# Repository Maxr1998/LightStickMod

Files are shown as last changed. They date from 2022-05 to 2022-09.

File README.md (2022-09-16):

# Light Stick Mod

Modding the LOOΠΔ light stick with a custom PCB/firmware, rechargeable battery and a companion Android app for wireless control.

<p align="center">
Photo of the finished light stick
</p>

## [pcb](pcb)

Designed in KiCAD, manufactured by JLCPCB. Uses the ESP32 as a controller.

## [firmware](firmware)

Built with [esphome.io](https://esphome.io).
Supports WiFi control, integrates with Home Assistant, introduces [animated effects](https://gfycat.com/grandcharminghogget).  
Thanks to deep sleep support, idle battery drain can be kept to a minimum.

## [app](app)

Companion app for Android to allow wireless control via Bluetooth LE. Written in Kotlin, using JetPack Compose for the UI.

## [build log](build-log.md)

Write-up on how I modded it.

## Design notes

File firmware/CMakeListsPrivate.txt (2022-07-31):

# !!! WARNING !!! AUTO-GENERATED FILE, PLEASE DO NOT MODIFY IT AND USE
# https://docs.platformio.org/page/projectconf/section_env_build.html#build-flags
#
# If you need to override existing CMake configuration or add extra,
# please create `CMakeListsUser.txt` in the root of project.
# The `CMakeListsUser.txt` will not be overwritten by PlatformIO.

set(CMAKE_CONFIGURATION_TYPES "lightstick" CACHE STRING "Build Types reflect PlatformIO Environments" FORCE)

SET(CMAKE_C_COMPILER "$ENV{HOME}/.platformio/packages/toolchain-xtensa32/bin/xtensa-esp32-elf-gcc")
SET(CMAKE_CXX_COMPILER "$ENV{HOME}/.platformio/packages/toolchain-xtensa32/bin/xtensa-esp32-elf-g++")
SET(CMAKE_CXX_FLAGS "-fno-rtti -fno-exceptions -std=gnu++11 -Wno-sign-compare -Wno-unused-but-set-variable -Wno-unused-variable -fno-exceptions -Os -g3 -Wall -nostdlib -Wpointer-arith -Wno-error=unused-but-set-variable -Wno-error=unused-variable -mlongcalls -ffunction-sections -fdata-sections -fstrict-volatile-bitfields -Wno-error=deprecated-declarations -Wno-error=unused-function -Wno-unused-parameter -Wno-sign-compare -fstack-protector -fexceptions -Werror=reorder")
SET(CMAKE_C_FLAGS "-std=gnu99 -Wno-old-style-declaration -Wno-sign-compare -Wno-unused-but-set-variable -Wno-unused-variable -fno-exceptions -Os -g3 -Wall -nostdlib -Wpointer-arith -Wno-error=unused-but-set-variable -Wno-error=unused-variable -mlongcalls -ffunction-sections -fdata-sections -fstrict-volatile-bitfields -Wno-error=deprecated-declarations -Wno-error=unused-function -Wno-unused-parameter -Wno-sign-compare -fstack-protector -fexceptions -Werror=reorder")

SET(CMAKE_C_STANDARD 99)
set(CMAKE_CXX_STANDARD 11)

SET(CMAKE_BUILD_DIR "${CMAKE_CURRENT_LIST_DIR}/.esphome/build/lightstick")

#if (CMAKE_BUILD_TYPE MATCHES "lightstick")
    add_definitions(-DPLATFORMIO=60103)
    add_definitions(-DARDUINO_ESP32_DEV)
    add_definitions(-DESPHOME_LOG_LEVEL=ESPHOME_LOG_LEVEL_INFO)
    add_definitions(-DUSE_ARDUINO)
    add_definitions(-DUSE_ESP32)
    add_definitions(-DUSE_ESP32_FRAMEWORK_ARDUINO)
    add_definitions(-DUSE_ESP32_VARIANT_ESP32)
    add_definitions(-DESP32)
    add_definitions(-DESP_PLATFORM)
    add_definitions(-DF_CPU=240000000L)
    add_definitions(-DHAVE_CONFIG_H)
    add_definitions(-DMBEDTLS_CONFIG_FILE=\"mbedtls/esp_config.h\")
    add_definitions(-DARDUINO=10805)
    add_definitions(-DARDUINO_ARCH_ESP32)
    add_definitions(-DARDUINO_VARIANT=\"esp32\")
    add_definitions(-DARDUINO_BOARD=\"Espressif\ ESP32\ Dev\ Module\")

    include_directories("${CMAKE_CURRENT_LIST_DIR}/")
    include_directories("${CMAKE_BUILD_DIR}/include")
    include_directories("${CMAKE_BUILD_DIR}/src")
    include_directories("${CMAKE_BUILD_DIR}/.pio/libdeps/lightstick/ArduinoJson/src")
    include_directories("${CMAKE_BUILD_DIR}/.pio/libdeps/lightstick/ESPAsyncWebServer-esphome/src")
    include_directories("${CMAKE_BUILD_DIR}/.pio/libdeps/lightstick/AsyncTCP-esphome/src")
    include_directories("$ENV{HOME}/.platformio/packages/framework-arduinoespressif32/libraries/ESPmDNS/src")
    include_directories("$ENV{HOME}/.platformio/packages/framework-arduinoespressif32/libraries/Update/src")
    include_directories("$ENV{HOME}/.platformio/packages/framework-arduinoespressif32/libraries/FS/src")
    include_directories("$ENV{HOME}/.platformio/packages/framework-arduinoespressif32/libraries/WiFi/src")
    include_directories("$ENV{HOME}/.platformio/packages/framework-arduinoespressif32/tools/sdk/include/config")
    include_directories("$ENV{HOME}/.platformio/packages/framework-arduinoespressif32/tools/sdk/include/app_trace")
    include_directories("$ENV{HOME}/.platformio/packages/framework-arduinoespressif32/tools/sdk/include/app_update")
    include_directories("$ENV{HOME}/.platformio/packages/framework-arduinoespressif32/tools/sdk/include/asio")
    include_directories("$ENV{HOME}/.platformio/packages/framework-arduinoespressif32/tools/sdk/include/bootloader_support")
    include_directories("$ENV{HOME}/.platformio/packages/framework-arduinoespressif32/tools/sdk/include/bt")
    include_directories("$ENV{HOME}/.platformio/packages/framework-arduinoespressif32/tools/sdk/include/coap")
    include_directories("$ENV{HOME}/.platformio/packages/framework-arduinoespressif32/tools/sdk/include/console")
    include_directories("$ENV{HOME}/.platformio/packages/framework-arduinoespressif32/tools/sdk/include/driver")
    include_directories("$ENV{HOME}/.platformio/packages/framework-arduinoespressif32/tools/sdk/include/efuse")
    include_directories("$ENV{HOME}/.platformio/packages/framework-arduinoespressif32/tools/sdk/include/esp-tls")
    include_directories("$ENV{HOME}/.platformio/packages/framework-arduinoespressif32/tools/sdk/include/esp32")
    include_directories("$ENV{HOME}/.platformio/packages/framework-arduinoespressif32/tools/sdk/include/esp_adc_cal")
    include_directories("$ENV{HOME}/.platformio/packages/framework-arduinoespressif32/tools/sdk/include/esp_event")
    include_directories("$ENV{HOME}/.platformio/packages/framework-arduinoespressif32/tools/sdk/include/esp_http_client")
    include_directories("$ENV{HOME}/.platformio/packages/framework-arduinoespressif32/tools/sdk/include/esp_http_server")
    include_directories("$ENV{HOME}/.platformio/packages/framework-arduinoespressif32/tools/sdk/include/esp_https_ota")
    include_directories("$ENV{HOME}/.platformio/packages/framework-arduinoespressif32/tools/sdk/include/esp_https_server")
    include_directories("$ENV{HOME}/.platformio/packages/framework-arduinoespressif32/tools/sdk/include/esp_ringbuf")
    include_directories("$ENV{HOME}/.platformio/packages/framework-arduinoespressif32/tools/sdk/include/esp_websocket_client")
    include_directories("$ENV{HOME}/.platformio/packages/framework-arduinoespressif32/tools/sdk/include/espcoredump")
    include_directories("$ENV{HOME}/.platformio/packages/framework-arduinoespressif32/tools/sdk/include/ethernet")
    include_directories("$ENV{HOME}/.platformio/packages/framework-arduinoespressif32/tools/sdk/include/expat")
    include_directories("$ENV{HOME}/.platformio/packages/framework-arduinoespressif32/tools/sdk/include/fatfs")
    include_directories("$ENV{HOME}/.platformio/packages/framework-arduinoespressif32/tools/sdk/include/freemodbus")
    include_directories("$ENV{HOME}/.platformio/packages/framework-arduinoespressif32/tools/sdk/include/freertos")
    include_directories("$ENV{HOME}/.platformio/packages/framework-arduinoespressif32/tools/sdk/include/heap")
    include_directories("$ENV{HOME}/.platformio/packages/framework-arduinoespressif32/tools/sdk/include/idf_test")
    include_directories("$ENV{HOME}/.platformio/packages/framework-arduinoespressif32/tools/sdk/include/jsmn")
    include_directories("$ENV{HOME}/.platformio/packages/framework-arduinoespressif32/tools/sdk/include/json")
    include_directories("$ENV{HOME}/.platformio/packages/framework-arduinoespressif32/tools/sdk/include/libsodium")
    include_directories("$ENV{HOME}/.platformio/packages/framework-arduinoespressif32/tools/sdk/include/log")
    include_directories("$ENV{HOME}/.platformio/packages/framework-arduinoespressif32/tools/sdk/include/lwip")
    include_directories("$ENV{HOME}/.platformio/packages/framework-arduinoespressif32/tools/sdk/include/mbedtls")
    include_directories("$ENV{HOME}/.platformio/packages/framework-arduinoespressif32/tools/sdk/include/mdns")
    include_directories("$ENV{HOME}/.platformio/packages/framework-arduinoespressif32/tools/sdk/include/micro-ecc")
    include_directories("$ENV{HOME}/.platformio/packages/framework-arduinoespressif32/tools/sdk/include/mqtt")
    include_directories("$ENV{HOME}/.platformio/packages/framework-arduinoespressif32/tools/sdk/include/newlib")
    include_directories("$ENV{HOME}/.platformio/packages/framework-arduinoespressif32/tools/sdk/include/nghttp")
    include_directories("$ENV{HOME}/.platformio/packages/framework-arduinoespressif32/tools/sdk/include/nvs_flash")
    include_directories("$ENV{HOME}/.platformio/packages/framework-arduinoespressif32/tools/sdk/include/openssl")
    include_directories("$ENV{HOME}/.platformio/packages/framework-arduinoespressif32/tools/sdk/include/protobuf-c")
    include_directories("$ENV{HOME}/.platformio/packages/framework-arduinoespressif32/tools/sdk/include/protocomm")
    include_directories("$ENV{HOME}/.platformio/packages/framework-arduinoespressif32/tools/sdk/include/pthread")
    include_directories("$ENV{HOME}/.platformio/packages/framework-arduinoespressif32/tools/sdk/include/sdmmc")
    include_directories("$ENV{HOME}/.platformio/packages/framework-arduinoespressif32/tools/sdk/include/smartconfig_ack")
    include_directories("$ENV{HOME}/.platformio/packages/framework-arduinoespressif32/tools/sdk/include/soc")
    include_directories("$ENV{HOME}/.platformio/packages/framework-arduinoespressif32/tools/sdk/include/spi_flash")
    include_directories("$ENV{HOME}/.platformio/packages/framework-arduinoespressif32/tools/sdk/include/spiffs")
    include_directories("$ENV{HOME}/.platformio/packages/framework-arduinoespressif32/tools/sdk/include/tcp_transport")
    include_directories("$ENV{HOME}/.platformio/packages/framework-arduinoespressif32/tools/sdk/include/tcpip_adapter")
    include_directories("$ENV{HOME}/.platformio/packages/framework-arduinoespressif32/tools/sdk/include/ulp")
    include_directories("$ENV{HOME}/.platformio/packages/framework-arduinoespressif32/tools/sdk/include/unity")
    include_directories("$ENV{HOME}/.platformio/packages/framework-arduinoespressif32/tools/sdk/include/vfs")
    include_directories("$ENV{HOME}/.platformio/packages/framework-arduinoespressif32/tools/sdk/include/wear_levelling")
    include_directories("$ENV{HOME}/.platformio/packages/framework-arduinoespressif32/tools/sdk/include/wifi_provisioning")
    include_directories("$ENV{HOME}/.platformio/packages/framework-arduinoespressif32/tools/sdk/include/wpa_supplicant")
    include_directories("$ENV{HOME}/.platformio/packages/framework-arduinoespressif32/tools/sdk/include/xtensa-debug-module")
    include_directories("$ENV{HOME}/.platformio/packages/framework-arduinoespressif32/tools/sdk/include/esp-face")
    include_directories("$ENV{HOME}/.platformio/packages/framework-arduinoespressif32/tools/sdk/include/esp32-camera")
    include_directories("$ENV{HOME}/.platformio/packages/framework-arduinoespressif32/tools/sdk/include/fb_gfx")
    include_directories("$ENV{HOME}/.platformio/packages/framework-arduinoespressif32/cores/esp32")
    include_directories("$ENV{HOME}/.platformio/packages/framework-arduinoespressif32/variants/esp32")
    include_directories("$ENV{HOME}/.platformio/lib/Adafruit BME280 Library")
    include_directories("$ENV{HOME}/.platformio/lib/Adafruit Unified Sensor")
    include_directories("$ENV{HOME}/.platformio/lib/FastLED")
    include_directories("$ENV{HOME}/.platformio/packages/framework-arduinoespressif32/libraries/ArduinoOTA/src")
    include_directories("$ENV{HOME}/.platformio/packages/framework-arduinoespressif32/libraries/AsyncUDP/src")
    include_directories("$ENV{HOME}/.platformio/packages/framework-arduinoespressif32/libraries/AzureIoT/src")
    include_directories("$ENV{HOME}/.platformio/packages/framework-arduinoespressif32/libraries/BLE/src")
    include_directories("$ENV{HOME}/.platformio/packages/framework-arduinoespressif32/libraries/BluetoothSerial/src")
    include_directories("$ENV{HOME}/.platformio/packages/framework-arduinoespressif32/libraries/DNSServer/src")
    include_directories("$ENV{HOME}/.platformio/packages/framework-arduinoespressif32/libraries/EEPROM/src")
    include_directories("$ENV{HOME}/.platformio/packages/framework-arduinoespressif32/libraries/ESP32/src")
    include_directories("$ENV{HOME}/.platformio/packages/framework-arduinoespressif32/libraries/FFat/src")
    include_directories("$ENV{HOME}/.platformio/packages/framework-arduinoespressif32/libraries/HTTPClient/src")
    include_directories("$ENV{HOME}/.platformio/packages/framework-arduinoespressif32/libraries/HTTPUpdate/src")
    include_directories("$ENV{HOME}/.platformio/packages/framework-arduinoespressif32/libraries/HTTPUpdateServer/src")
    include_directories("$ENV{HOME}/.platformio/packages/framework-arduinoespressif32/libraries/NetBIOS/src")
    include_directories("$ENV{HOME}/.platformio/packages/framework-arduinoespressif32/libraries/Preferences/src")
    include_directories("$ENV{HOME}/.platformio/packages/framework-arduinoespressif32/libraries/SD/src")
    include_directories("$ENV{HOME}/.platformio/packages/framework-arduinoespressif32/libraries/SD_MMC/src")
    include_directories("$ENV{HOME}/.platformio/packages/framework-arduinoespressif32/libraries/SPI/src")
    include_directories("$ENV{HOME}/.platformio/packages/framework-arduinoespressif32/libraries/SPIFFS/src")
    include_directories("$ENV{HOME}/.platformio/packages/framework-arduinoespressif32/libraries/SimpleBLE/src")
    include_directories("$ENV{HOME}/.platformio/packages/framework-arduinoespressif32/libraries/Ticker/src")
    include_directories("$ENV{HOME}/.platformio/packages/framework-arduinoespressif32/libraries/WebServer/src")
    include_directories("$ENV{HOME}/.platformio/packages/framework-arduinoespressif32/libraries/WiFiClientSecure/src")
    include_directories("$ENV{HOME}/.platformio/packages/framework-arduinoespressif32/libraries/WiFiProv/src")
    include_directories("$ENV{HOME}/.platformio/packages/framework-arduinoespressif32/libraries/Wire/src")
    include_directories("$ENV{HOME}/.platformio/packages/toolchain-xtensa32/xtensa-esp32-elf/include/c++/5.2.0")
    include_directories("$ENV{HOME}/.platformio/packages/toolchain-xtensa32/xtensa-esp32-elf/include/c++/5.2.0/xtensa-esp32-elf")
    include_directories("$ENV{HOME}/.platformio/packages/toolchain-xtensa32/lib/gcc/xtensa-esp32-elf/5.2.0/include-fixed")
    include_directories("$ENV{HOME}/.platformio/packages/toolchain-xtensa32/lib/gcc/xtensa-esp32-elf/5.2.0/include")
    include_directories("$ENV{HOME}/.platformio/packages/toolchain-xtensa32/xtensa-esp32-elf/include")

    FILE(GLOB_RECURSE EXTRA_LIB_SOURCES
        ${CMAKE_BUILD_DIR}/.pio/libdeps/lightstick/*.*
    )
#endif()

FILE(GLOB_RECURSE SRC_LIST
    ${CMAKE_CURRENT_LIST_DIR}/*.*
    ${CMAKE_BUILD_DIR}/src/*.*
    ${CMAKE_BUILD_DIR}/lib/*.*
    ${CMAKE_BUILD_DIR}/test/*.*
)

list(APPEND SRC_LIST ${EXTRA_LIB_SOURCES})

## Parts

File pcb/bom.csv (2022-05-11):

Comment | Designator | Footprint | LCSC Part Number
10K | R1,R2 | 0805 | C17414
1K | R3,R4,R5,R6 | 0805 | C17513
10uF | C1 | 0805 | C32635
BC817 | Q1,Q2,Q3,Q4 | SOT-23-3 | C126908
AMS1117 | U1 | SOT-223 | C6186
ESP32 | U2 | SMD38 | C701342
Slide Switch | SW1 | SMD | C431541
6x6x5mm Tactile Switch | SW2 | SMD | C782827
JST PH1 2mm Connector 5 Pin | J1 | CONN-SMD | C146056

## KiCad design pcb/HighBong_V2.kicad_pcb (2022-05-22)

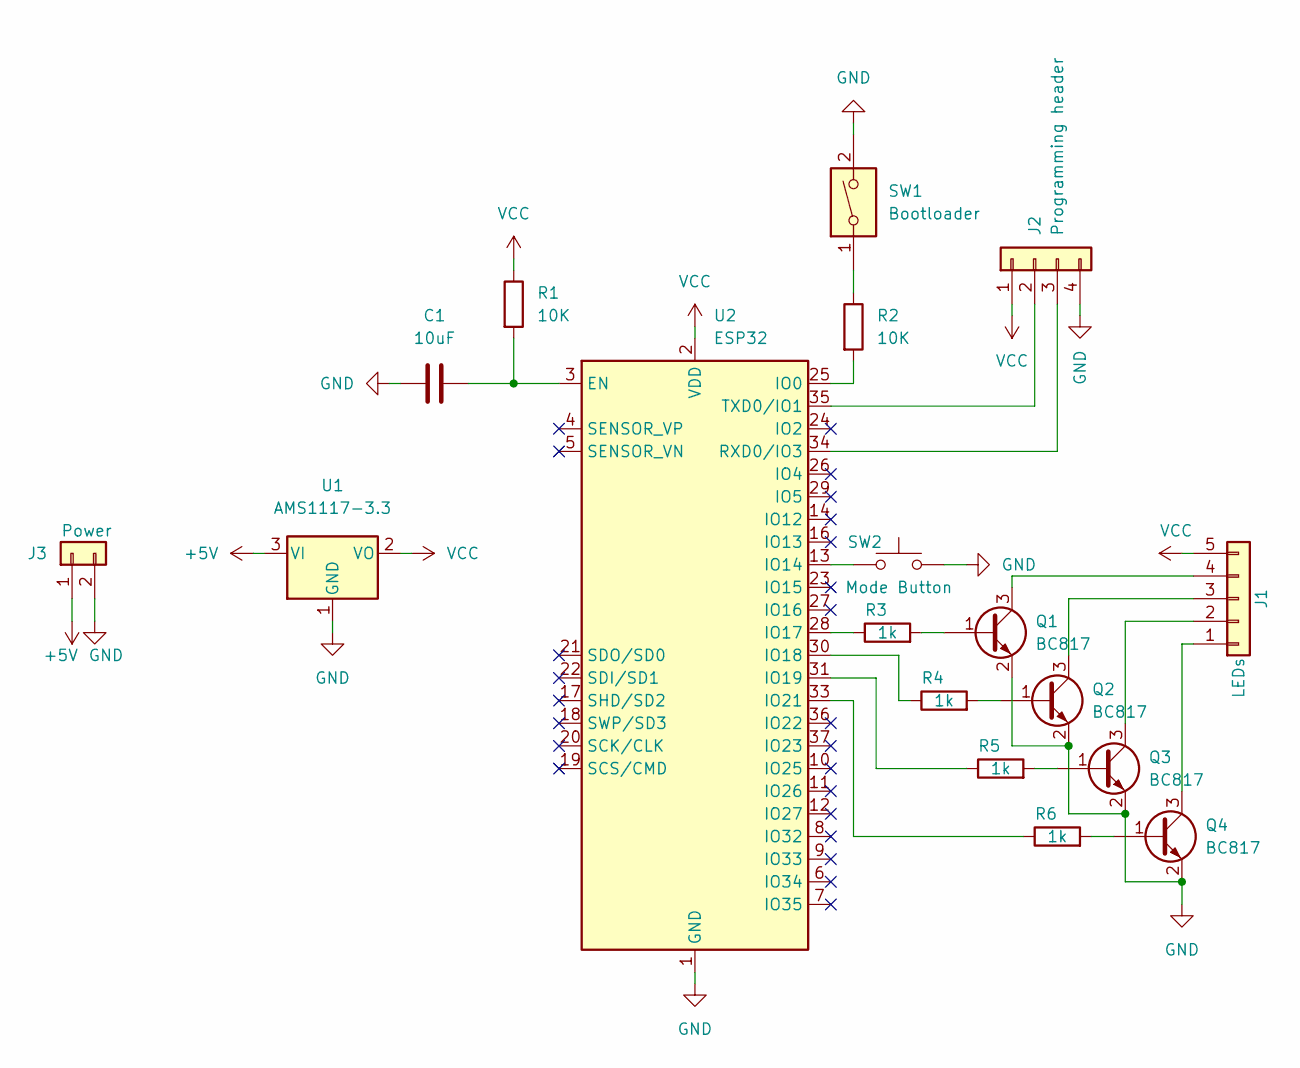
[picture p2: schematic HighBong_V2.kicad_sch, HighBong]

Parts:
C1: 10uF; C_0805_2012Metric_Pad1.18x1.45mm_HandSolder
J1: LEDs; JST_PH_B5B-PH-SM4-TB_1x05-1MP_P2.00mm_Vertical
J2: Programming header; PinHeader_1x04_P2.54mm_Vertical
J3: Power; JST_PH_B2B-PH-SM4-TB_1x02-1MP_P2.00mm_Vertical
Q1, Q2, Q3, Q4: BC817; SOT-23
R1, R2: 10K; R_0805_2012Metric_Pad1.20x1.40mm_HandSolder
R3, R4, R5, R6: 1k; R_0805_2012Metric_Pad1.20x1.40mm_HandSolder
SW1: Bootloader; KPS-1290
SW2: Mode Button; SW_Push_1P1T_NO_6x6mm_H9.5mm
U1: AMS1117-3.3; SOT-223-3_TabPin2
U2: ESP32; ESP32-WROOM-32

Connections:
+5V: J3.1, U1.3 (VI)
GND: C1.2, J2.4, J3.2, Q1.2 (E), Q2.2 (E), Q3.2 (E), Q4.2 (E), SW1.2, SW2.2, U1.1 (GND), U2.1 (GND), U2.15 (GND), U2.38 (GND), U2.39 (GND)
unnamed: C1.1, R1.2, U2.3 (EN)
unnamed: J1.1, Q4.3 (C)
unnamed: J1.2, Q3.3 (C)
unnamed: J1.3, Q2.3 (C)
unnamed: J1.4, Q1.3 (C)
unnamed: J2.2, U2.35 (TXD0/IO1)
unnamed: J2.3, U2.34 (RXD0/IO3)
unnamed: Q1.1 (B), R3.2
unnamed: Q2.1 (B), R4.2
unnamed: Q3.1 (B), R5.2
unnamed: Q4.1 (B), R6.2
unnamed: R2.1, SW1.1
unnamed: R2.2, U2.25 (IO0)
unnamed: R3.1, U2.28 (IO17)
unnamed: R4.1, U2.30 (IO18)
unnamed: R5.1, U2.31 (IO19)
unnamed: R6.1, U2.33 (IO21)
unnamed: SW2.1, U2.13 (IO14)
VCC: J1.5, J2.1, R1.1, U1.2 (VO), U2.2 (VDD)

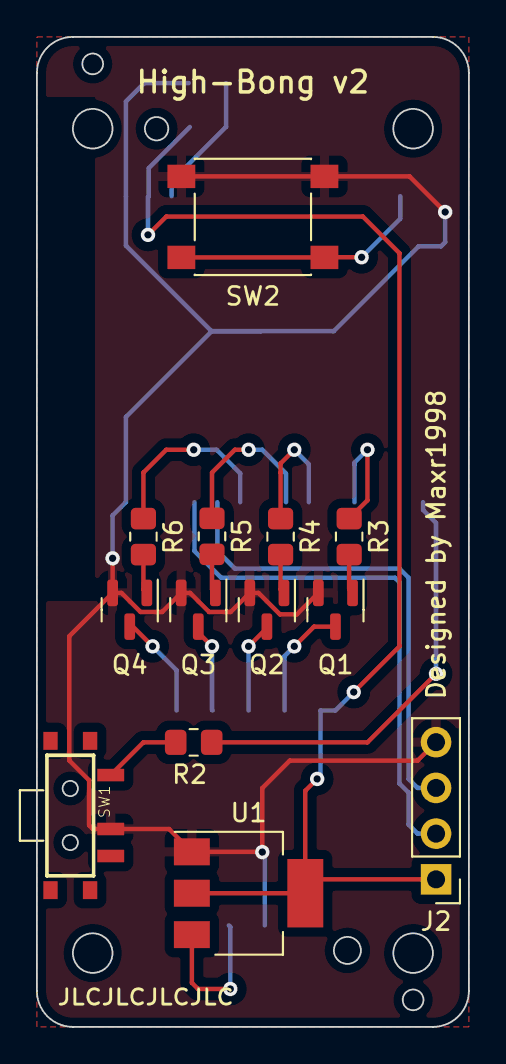
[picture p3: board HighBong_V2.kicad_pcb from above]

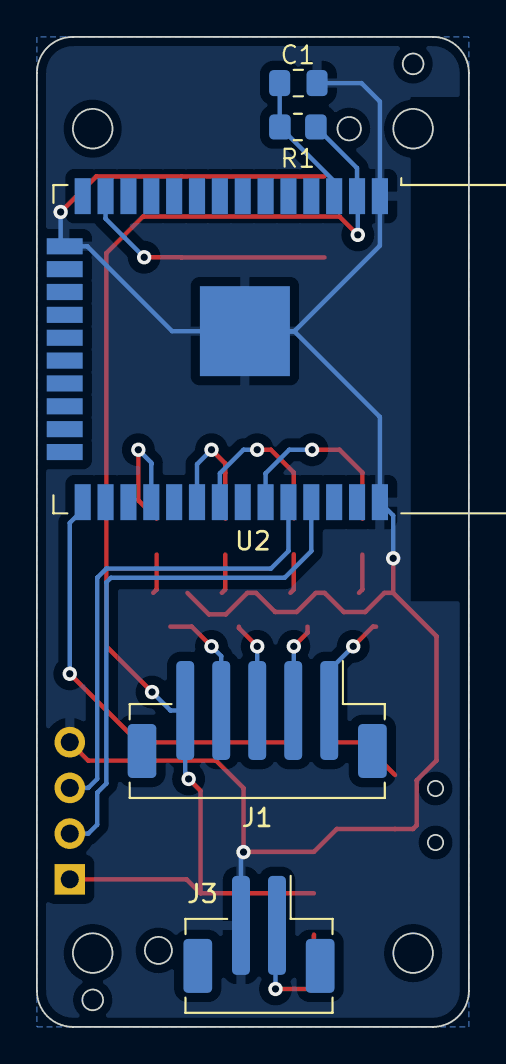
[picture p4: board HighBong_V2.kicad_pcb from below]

Board: 2 copper layers, 24.0 x 55.0 mm, 18 parts (5 on the bottom side), 21 nets.

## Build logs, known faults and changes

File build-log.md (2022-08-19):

# Build log

## Step 0: reverse-engineering and PCB design

First, I needed to understand how the light stick originally works.
Disassembly was very easy (only standard screws, yay!) and the PCB had some labels, which helped a lot.
To recreate the important properties for my own PCB, I had to do a lot of measuring,
did a few voltage readings, and carefully studied the design of the board.  
With that out of the way, I could create the [PCB](pcb).
Finding the correct components wasn't trivial, and I spent a lot of time picking the right transistor to control the LEDs.
For the rest, I selected equivalent parts where applicable, and added appropriate components for new behavior.
A bit of layouting and routing later, everything seemed fine, and I had a flawless design to put into production.
*Or so I thought.* More on that later.

## Step 1: PCB assembly

<p align="center">
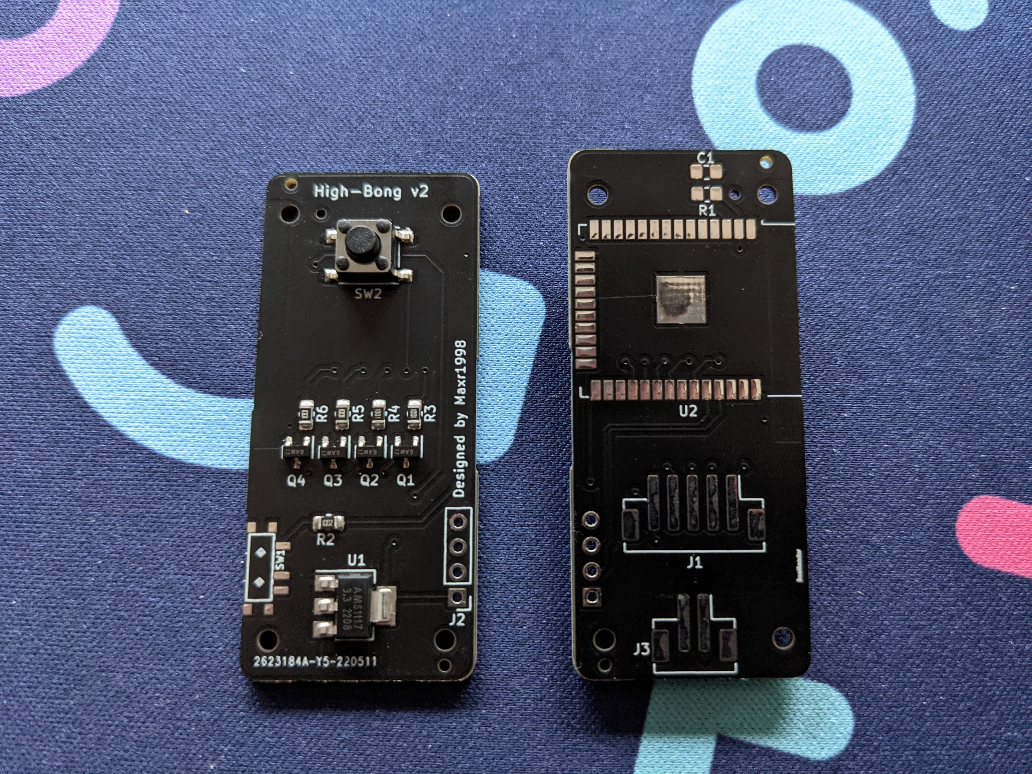
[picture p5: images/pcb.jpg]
PCB as delivered

</p>

…at least, partially.
Most components were already soldered by JLCPCB, since I chose to have one side of the board pre-assembled.
They did a very good job with it, in my opinion, just like on a previous order. It was also decently cheap.
Because I could only get one side assembled and them not having some parts, I needed to do the rest of the soldering myself.

<p align="center">
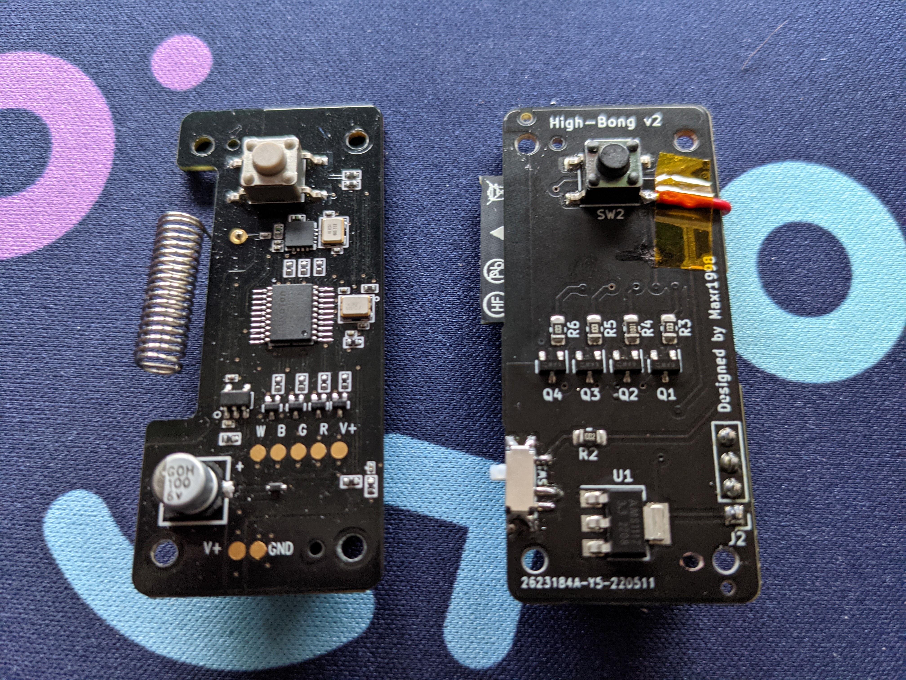
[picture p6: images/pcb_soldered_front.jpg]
PCB soldered front

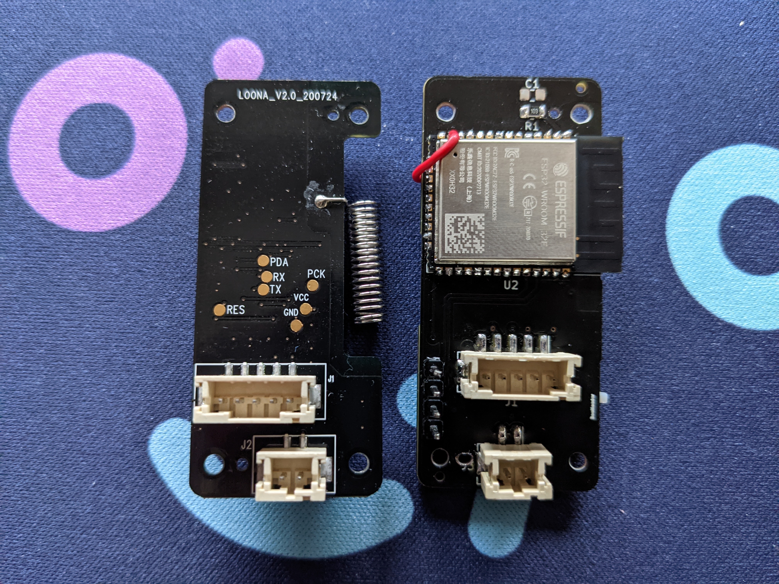
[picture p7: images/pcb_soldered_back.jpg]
PCB soldered back

<br>
Comparison of original PCB (left) with "fully" soldered replacement PCB (right) on both images, showing the front and back of it.
</p>

Unfortunately, it's already apparent here how many things I missed in my design (and that's not even all of them).
The pin I selected on the ESP32 didn't support wake up from deep sleep, so I had to add a wire to another pin and cut off the old trace.
Additionally, the screw holes weren't large enough, and I outright forgot one of the positioning holes
(see the drilled hole between the regulator U1 and the label of jumper J2).  
Talking about the regulator, it wasn't up to the required specs either:
The AMS-1117 I selected is great for use with USB power, but when employing it with a battery, the dropout of around 1 V is way too high.
Thus, I replaced it with a TPS73733 low-dropout regulator.
It has a different footprint, thus the solder job looks a bit *adventurous*.

<p align="center">
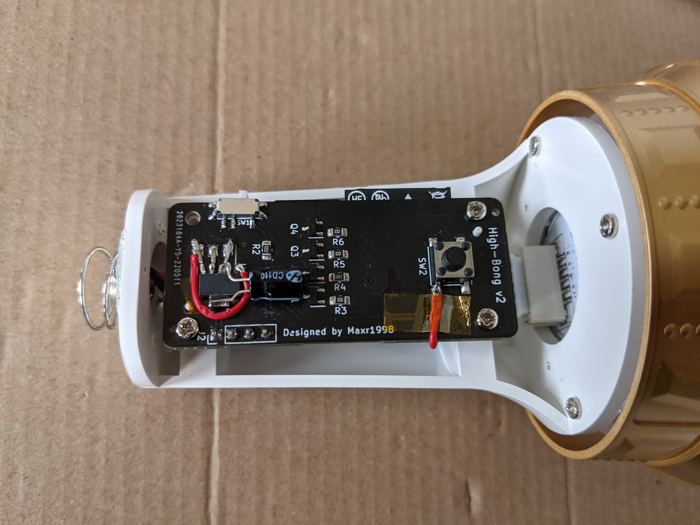
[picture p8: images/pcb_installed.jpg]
PCB installed in case

<br>
<i>It's not pretty, I know…</i>
</p>

With that, the first part of the mod is already done!

## Step 2: fitting the battery

The stock light stick is powered with three AAA batteries.
However, the battery life of it isn't great and because I expect the ESP32 to draw way more power than the original MCU,
mostly due to added wireless connectivity, I decided to replace the battery as well.
Coincidentally, the diameter of the handle is just enough to fit a 21700 li-ion cell.
Thus, I decided to order the one with the biggest capacity I could find, while making sure it also included a battery protection circuit.
Really don't want my light stick to suddenly go up in flames.

To fit the battery inside the handle, I first had to disassemble it:

<p align="center">
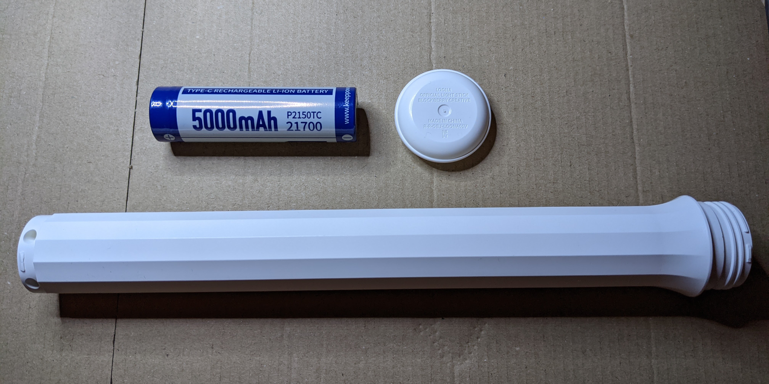
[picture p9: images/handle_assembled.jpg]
Light stick handle and battery

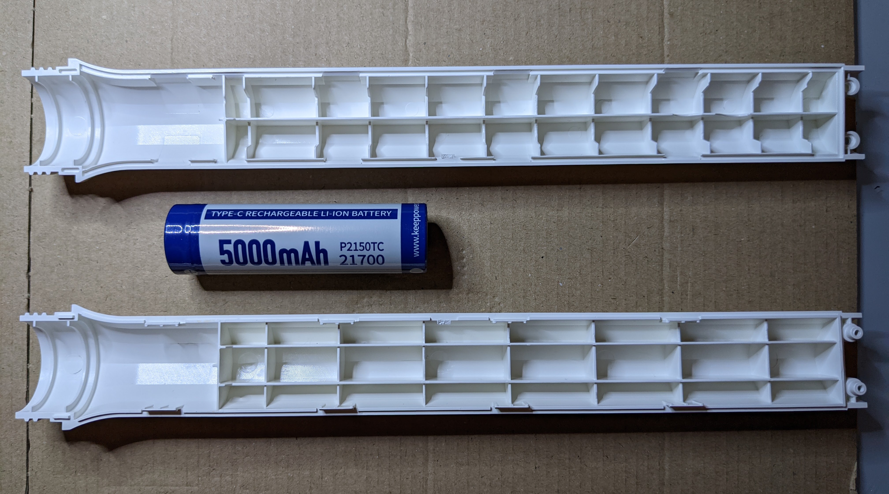
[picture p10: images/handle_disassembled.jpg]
Disassembled light stick handle

</p>

To make enough room for the battery, some parts of the reinforcement structures had to go.
Not gonna lie, using the rotary tool on the delicate plastics stressed me a bit, but thankfully, I didn't mess up anything.

<p align="center">
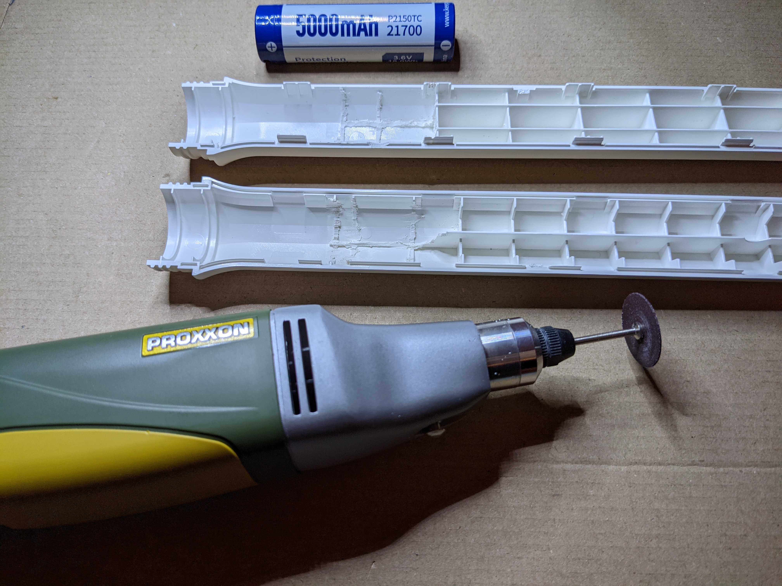
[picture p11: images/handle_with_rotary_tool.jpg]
Handle with the multi-tool

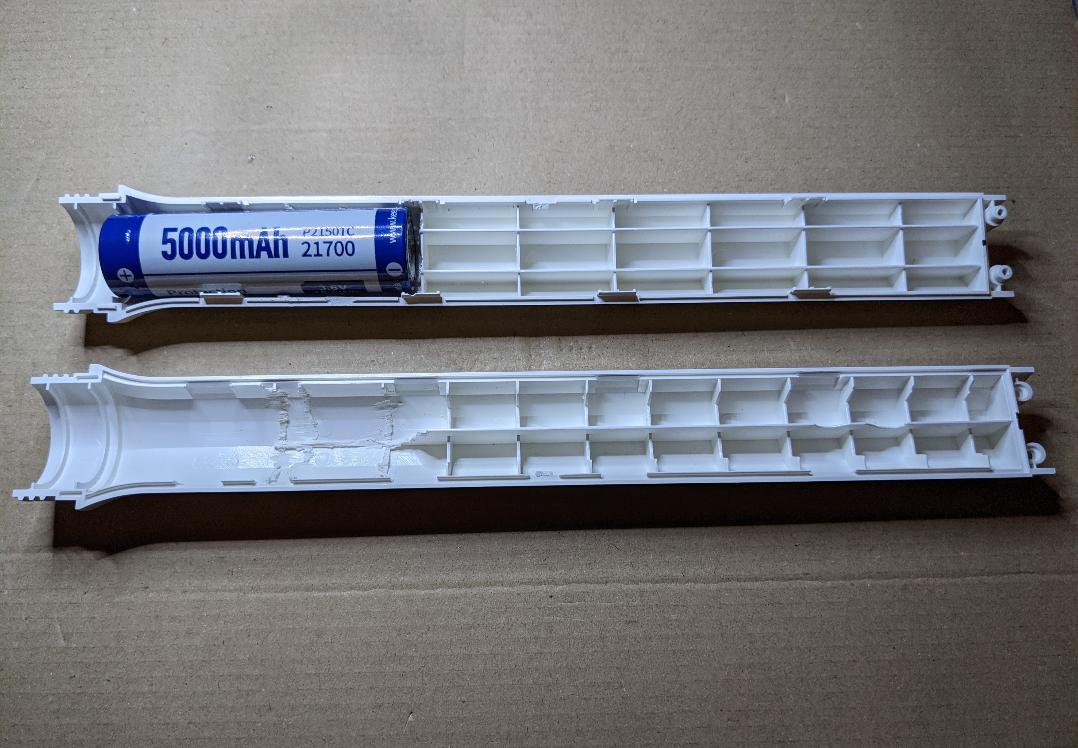
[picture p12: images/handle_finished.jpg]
Finished handle with battery in place

</p>

With the battery in place, I could move forward to install the charging circuit and do the wiring.
For that, I used a MCP73871-based board that I first had to configure by (re-)placing some resistors and capacitors.
[This guide][1] helped me a lot in the process.
Additionally, since the board was a bit too wide by default, I had to cut off a slice from the PCB.
To attach the battery to the light stick head, I re-used the original battery enclosure,
but modified it to work with my design.

After some wire soldering, this part was done as well!

<p align="center">
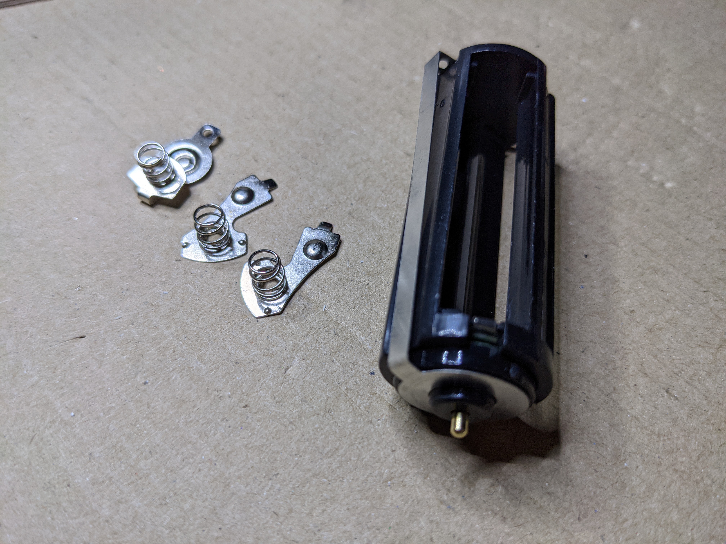
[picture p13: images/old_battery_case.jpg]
The original battery enclosure, partially disassembled

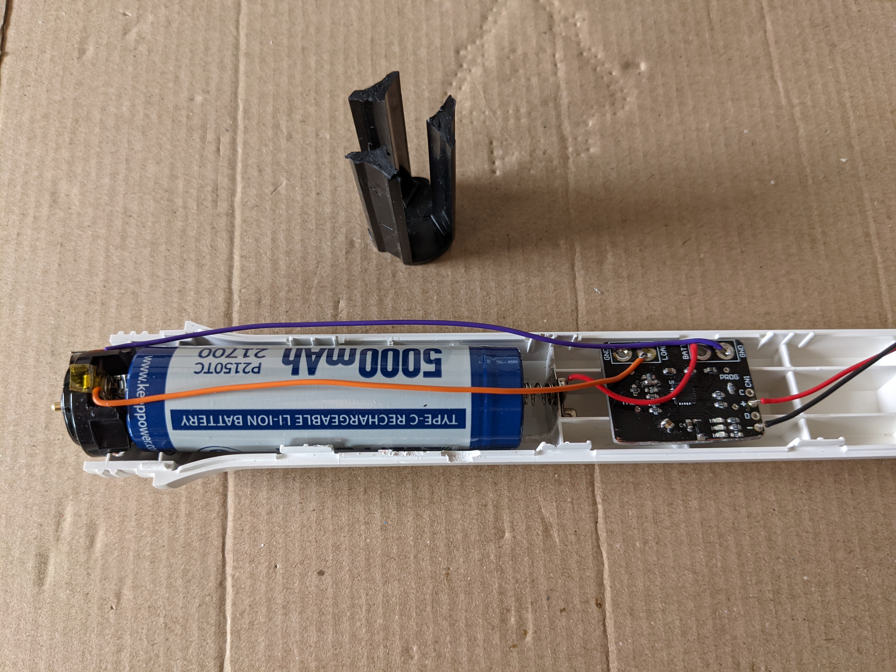
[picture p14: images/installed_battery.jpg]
Finished battery circuit

</p>

To charge the light stick, I added a USB-C port at the bottom lid.
I simply glued it into place and soldered wires onto it.

<p align="center">
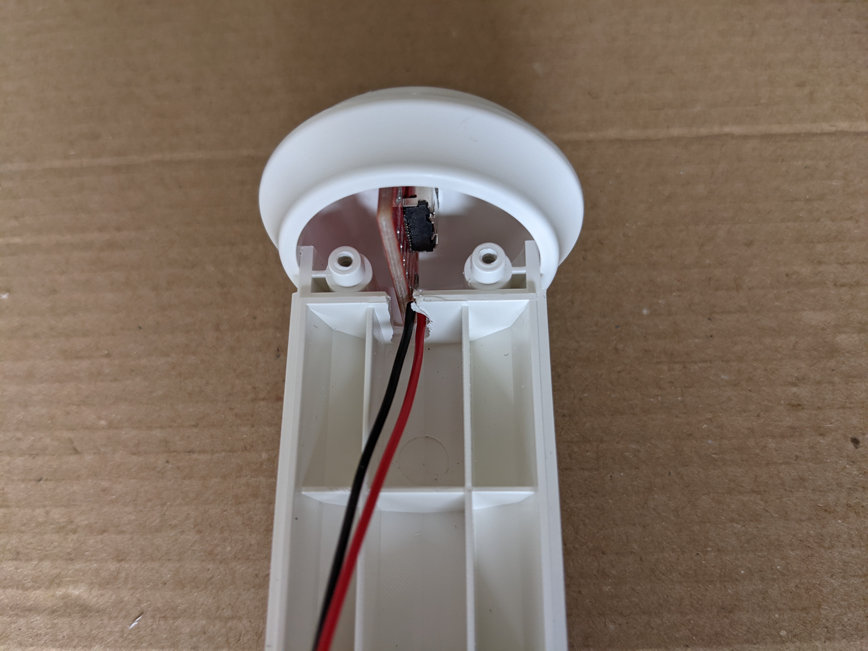
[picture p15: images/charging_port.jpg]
Charging port PCB and wiring

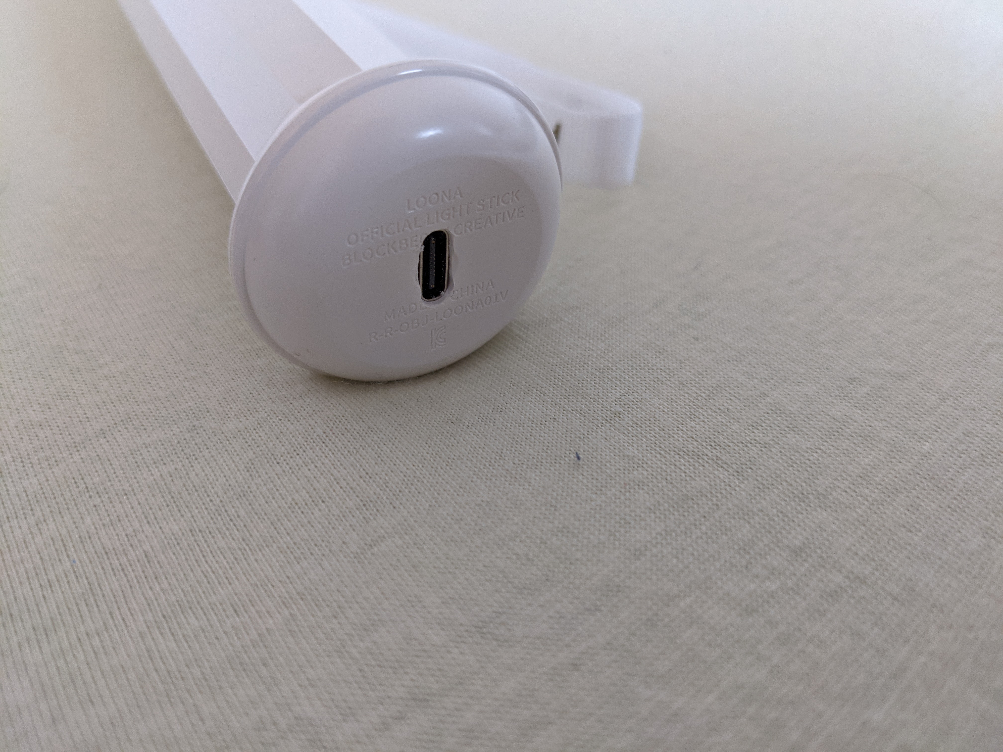
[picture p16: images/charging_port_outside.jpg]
Outer view of charging port

</p>

## Finished light stick

Finally, it is complete! Here is the reassembled light stick:

<p align="center">
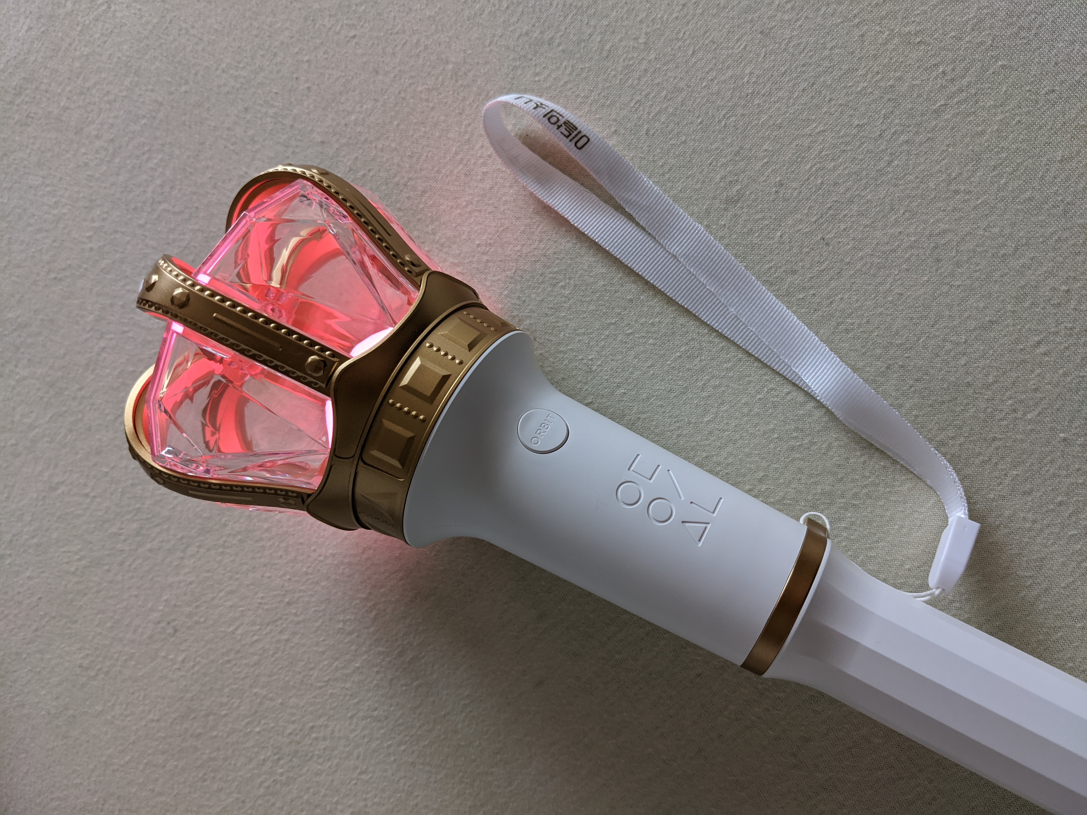
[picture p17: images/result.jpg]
Finished light stick

<br>
You don't see any difference from the outside, do you?
</p>

However, the hardware isn't the only part.
A custom [firmware](firmware) also needed to be written to actually introduce new features!

[1]: https://emariete.com/en/co2-meter-with-battery-well-done/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

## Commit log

2022-05-21 Fix issues with drill holes and swtich footprint
    [HighBong_V2.kicad_pcb, HighBong_V2.kicad_sch]
2022-05-21 Regenerate gerber files
    [HighBong_V2-B_Cu.gbl, HighBong_V2-B_Mask.gbs, HighBong_V2-B_Paste.gbp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]
2022-05-22 Move button to GPIO14
    [HighBong_V2.kicad_pcb, HighBong_V2.kicad_sch]
